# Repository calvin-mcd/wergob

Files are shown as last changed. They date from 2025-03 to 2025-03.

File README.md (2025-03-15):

# wergob

This is a pcb for the ergo board by _obabo called wergob!

## Layout

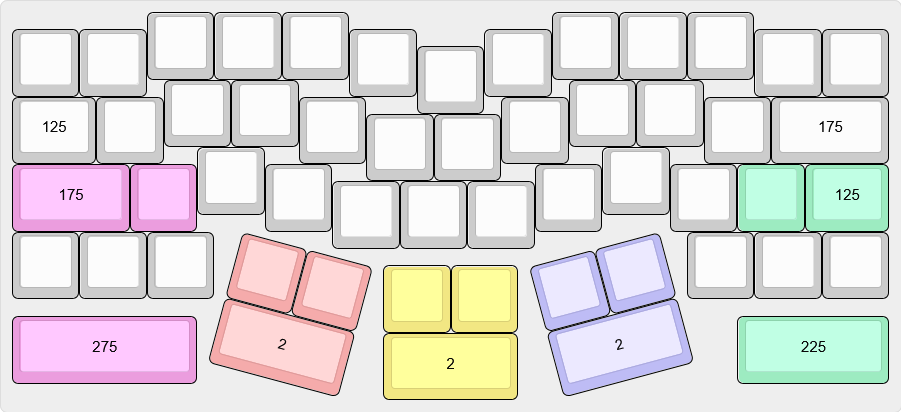
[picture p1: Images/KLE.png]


[Link](https://www.keyboard-layout-editor.com/#/gists/adf7cc06b15a428de764ebef3565cc50)

## Case

_obabo is designing a dedicated case for this unique layout!

## Todo

- [ ] order & test pcb
- [ ] design & test case
- [ ] create firmware

## Disclaimer

Please note that this project is a work in progress with no guarantees of a working outcome. No-one involved in this project is responsible for any usage issues that may arise. However, feel free to edit, modify and otherwise utilise these files.

## License

This project is released under the GPL v3 License. Please refer to the LICENCE file.

## Credits

big thanks to _obabo for the inspiring keyboard designs for our community! 

Any questions, contact Calvin\#0563 on Discord.

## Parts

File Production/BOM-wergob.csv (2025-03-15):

Comment | Designator | Footprint | LCSC | Quantity
10uF | C6 | C_0402_1005Metric | C15525 | 1
JST SH | J1 | JST_SH_SM04B-SRSS-TB_1x04-1MP_P1.00mm_Horizontal | C160404 | 1
10k | R1 | R_0402_1005Metric | C25744 | 1
100nF | C1,C2,C3,C4,C5,C7 | C_0402_1005Metric | C307331 | 6
1uF | C8,C9 | C_0402_1005Metric | C52923 | 2
XC6206PxxxMR-Regulator_Linear | U2 | SOT-23 | C5446 | 1
SKQGABE010 | SW1 | SW_Push_SPST_NO_Alps_SKRK | C561519 | 1
D_Small | D1,D10,D11,D12,D13,D14,D15,D16,D17,D18,D19,D2,D20,D21,D22,D23,D24,D25,D26,D27,D28,D29,D3,D30,D31,D32,D33,D34,D35,D36,D37,D38,D39,D4,D40,D41,D42,D43,D44,D45,D46,D47,D48,D49,D5,D6,D7,D8,D9 | D_SOD-123F | C64898 | 49
STM32F072CBT6 | U1 | LQFP-48_7x7mm_P0.5mm | C80488 | 1

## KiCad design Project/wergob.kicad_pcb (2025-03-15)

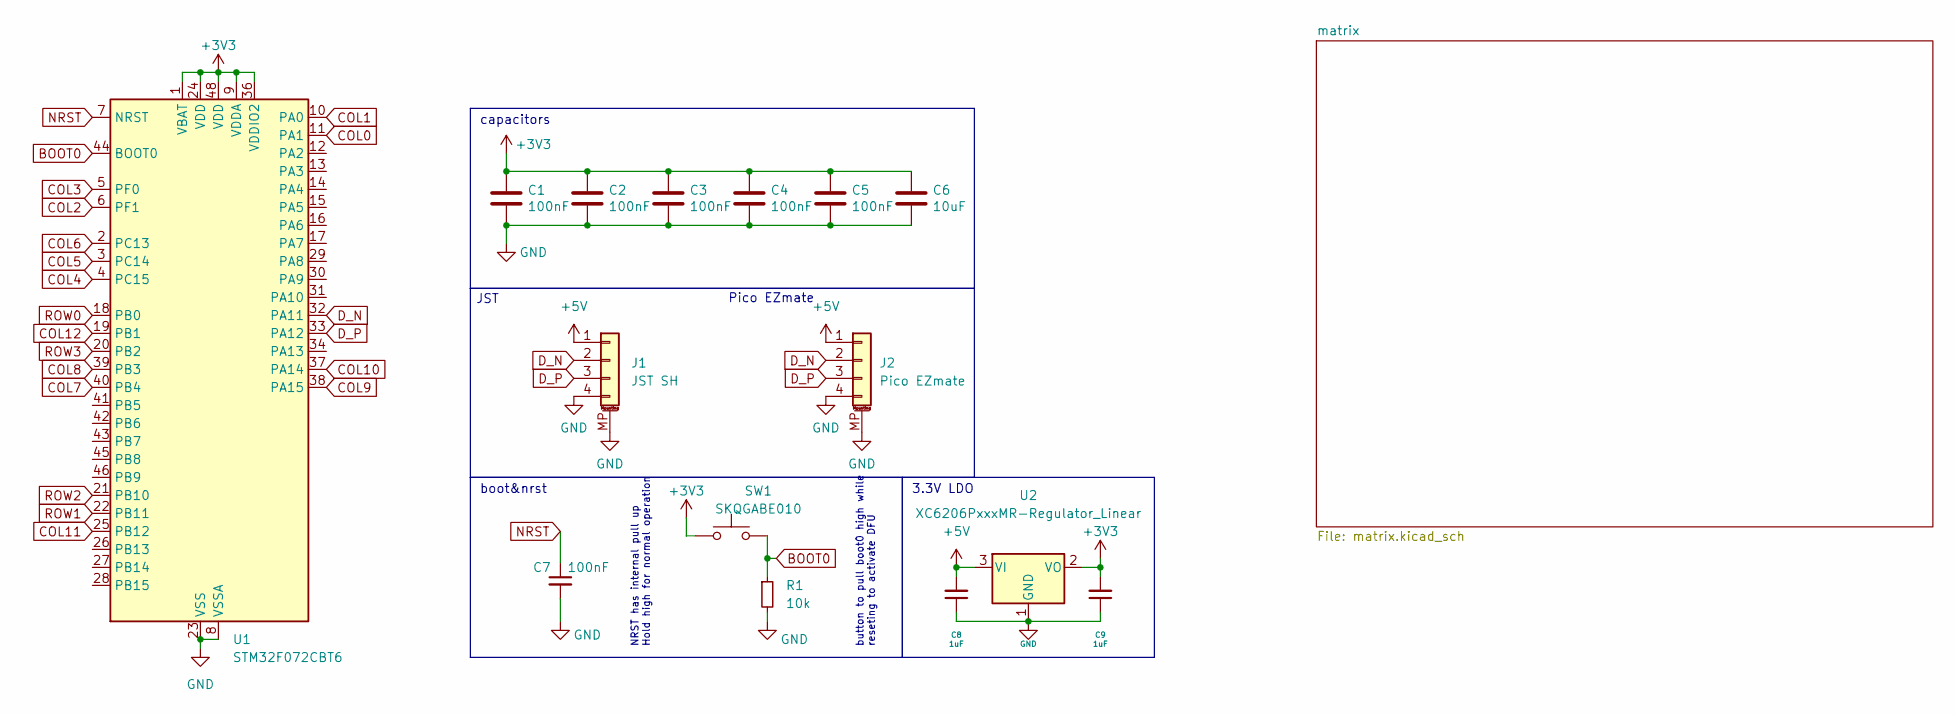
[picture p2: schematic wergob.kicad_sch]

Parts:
C1, C2, C3, C4, C5, C7: 100nF; C_0402_1005Metric; LCSC C307331
C6: 10uF; C_0402_1005Metric
C8, C9: 1uF; C_0402_1005Metric; LCSC C52923
J1: JST SH; JST_SH_SM04B-SRSS-TB_1x04-1MP_P1.00mm_Horizontal
J2: Pico EZmate; Molex_Pico-EZmate_78171-0004_1x04-1MP_P1.20mm_Vertical
R1: 10k; R_0402_1005Metric
SW1: SKQGABE010; SW_Push_SPST_NO_Alps_SKRK; LCSC C115351
U1: STM32F072CBT6; LQFP-48_7x7mm_P0.5mm; JlcRotOffset 90
U2: XC6206PxxxMR-Regulator_Linear; SOT-23; LCSC C5446

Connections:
+3V3: C1.1, C2.1, C3.1, C4.1, C5.1, C6.1, C9.2, SW1.1, U1.1 (VBAT), U1.9 (VDDA), U1.24 (VDD), U1.36 (VDDIO2), U1.48 (VDD), U2.2 (VO)
+5V: C8.2, J1.1, J2.1, U2.3 (VI)
BOOT0: R1.1, SW1.2, U1.44 (BOOT0)
COL0: U1.11 (PA1); also elsewhere on the board
COL1: U1.10 (PA0); also elsewhere on the board
COL2: U1.6 (PF1); also elsewhere on the board
COL3: U1.5 (PF0); also elsewhere on the board
COL4: U1.4 (PC15); also elsewhere on the board
COL5: U1.3 (PC14); also elsewhere on the board
COL6: U1.2 (PC13); also elsewhere on the board
COL7: U1.40 (PB4); also elsewhere on the board
COL8: U1.39 (PB3); also elsewhere on the board
COL9: U1.38 (PA15); also elsewhere on the board
COL10: U1.37 (PA14); also elsewhere on the board
COL11: U1.25 (PB12); also elsewhere on the board
COL12: U1.19 (PB1); also elsewhere on the board
D_N: J1.2, J2.2, U1.32 (PA11)
D_P: J1.3, J2.3, U1.33 (PA12)
GND: C1.2, C2.2, C3.2, C4.2, C5.2, C6.2, C7.2, C8.1, C9.1, J1.4, J1.MP (MountPin), J2.4, J2.MP (MountPin), R1.2, U1.8 (VSSA), U1.23 (VSS), U1.35 (VSS), U1.47 (VSS), U2.1 (GND)
NRST: C7.1, U1.7 (NRST)
ROW0: U1.18 (PB0); also elsewhere on the board
ROW1: U1.22 (PB11); also elsewhere on the board
ROW2: U1.21 (PB10); also elsewhere on the board
ROW3: U1.20 (PB2); also elsewhere on the board

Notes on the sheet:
JST
capacitors
NRST has internal pull up Hold high for normal operation
boot&nrst
button to pull boot0 high while reseting to activate DFU
Pico EZmate
3.3V LDO

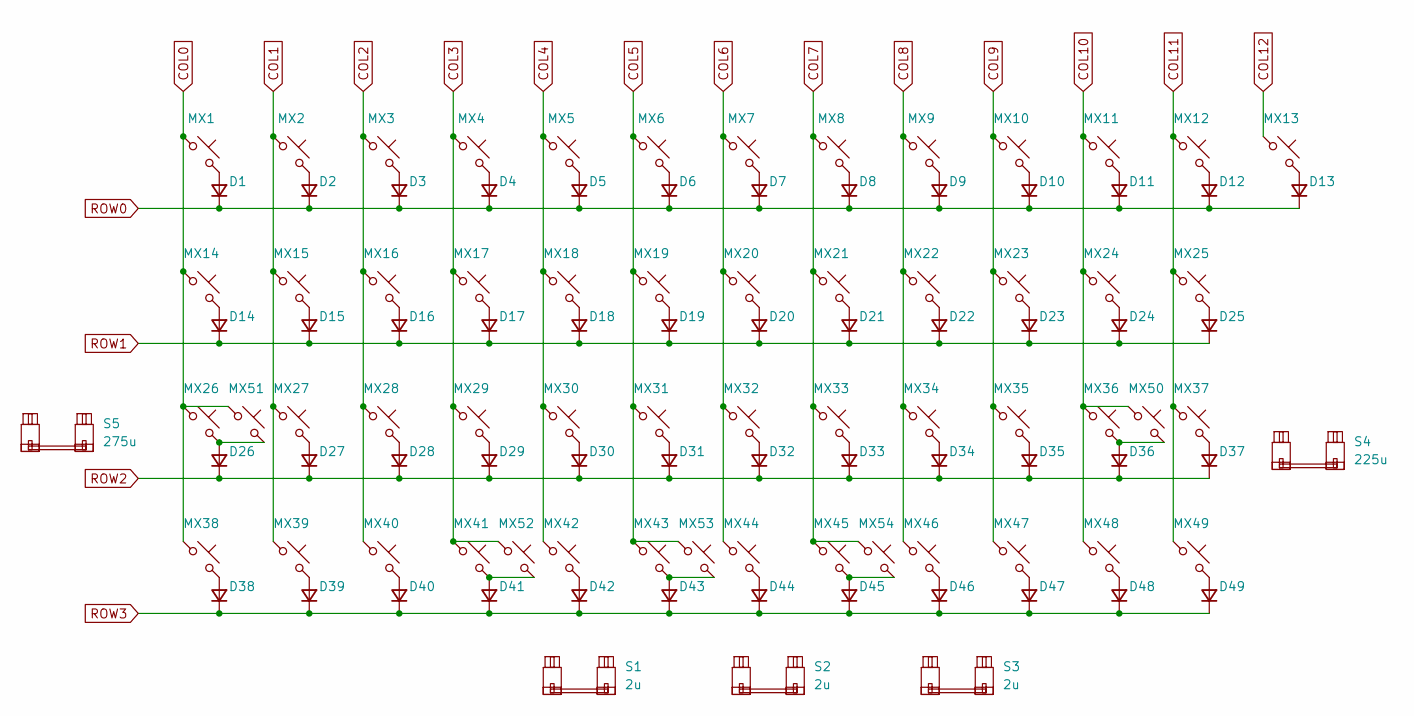
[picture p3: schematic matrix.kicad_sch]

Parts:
D1, D2, D3, D4, D5, D6, D7, D8, D9, D10, D11, D12, D13, D14, D15, D16, D17, D18, D19, D20, D21, D22, D23, D24, D25, D26, D27, D28, D29, D30, D31, D32, D33, D34, D35, D36, D37, D38, D39, D40, D41, D42, D43, D44, D45, D46, D47, D48, D49: D_Small; D_SOD-123F
MX1, MX2, MX3, MX4, MX5, MX6, MX7, MX8, MX9, MX10, MX11, MX12, MX13, MX15, MX16, MX17, MX18, MX19, MX20, MX21, MX22, MX23, MX24, MX27, MX28, MX29, MX30, MX31, MX32, MX33, MX34, MX35, MX36, MX38, MX39, MX40, MX41, MX42, MX43, MX44, MX45, MX46, MX47, MX48, MX49, MX50, MX51, MX52, MX53, MX54: MX_SW_solder; SW_MX_1u
MX14, MX37: MX_SW_solder; SW_MX_1.25u
MX25, MX26: MX_SW_solder; SW_MX_1.75u
S1, S2, S3: 2u; STAB_MX_P_2u
S4: 225u; STAB_MX_P_2.25u
S5: 275u; STAB_MX_P_2.75u

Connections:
COL0: MX1.1, MX14.1, MX26.1, MX38.1, MX51.1; also elsewhere on the board
COL1: MX2.1, MX15.1, MX27.1, MX39.1; also elsewhere on the board
COL2: MX3.1, MX16.1, MX28.1, MX40.1; also elsewhere on the board
COL3: MX4.1, MX17.1, MX29.1, MX41.1, MX52.1; also elsewhere on the board
COL4: MX5.1, MX18.1, MX30.1, MX42.1; also elsewhere on the board
COL5: MX6.1, MX19.1, MX31.1, MX43.1, MX53.1; also elsewhere on the board
COL6: MX7.1, MX20.1, MX32.1, MX44.1; also elsewhere on the board
COL7: MX8.1, MX21.1, MX33.1, MX45.1, MX54.1; also elsewhere on the board
COL8: MX9.1, MX22.1, MX34.1, MX46.1; also elsewhere on the board
COL9: MX10.1, MX23.1, MX35.1, MX47.1; also elsewhere on the board
COL10: MX11.1, MX24.1, MX36.1, MX48.1, MX50.1; also elsewhere on the board
COL11: MX12.1, MX25.1, MX37.1, MX49.1; also elsewhere on the board
COL12: MX13.1; also elsewhere on the board
unnamed: D1.2 (A), MX1.2
unnamed: D2.2 (A), MX2.2
unnamed: D3.2 (A), MX3.2
unnamed: D4.2 (A), MX4.2
unnamed: D5.2 (A), MX5.2
unnamed: D6.2 (A), MX6.2
unnamed: D7.2 (A), MX7.2
unnamed: D8.2 (A), MX8.2
unnamed: D9.2 (A), MX9.2
unnamed: D10.2 (A), MX10.2
unnamed: D11.2 (A), MX11.2
unnamed: D12.2 (A), MX12.2
unnamed: D13.2 (A), MX13.2
unnamed: D14.2 (A), MX14.2
unnamed: D15.2 (A), MX15.2
unnamed: D16.2 (A), MX16.2
unnamed: D17.2 (A), MX17.2
unnamed: D18.2 (A), MX18.2
unnamed: D19.2 (A), MX19.2
unnamed: D20.2 (A), MX20.2
unnamed: D21.2 (A), MX21.2
unnamed: D22.2 (A), MX22.2
unnamed: D23.2 (A), MX23.2
unnamed: D24.2 (A), MX24.2
unnamed: D25.2 (A), MX25.2
unnamed: D26.2 (A), MX26.2, MX51.2
unnamed: D27.2 (A), MX27.2
unnamed: D28.2 (A), MX28.2
unnamed: D29.2 (A), MX29.2
unnamed: D30.2 (A), MX30.2
unnamed: D31.2 (A), MX31.2
unnamed: D32.2 (A), MX32.2
unnamed: D33.2 (A), MX33.2
unnamed: D34.2 (A), MX34.2
unnamed: D35.2 (A), MX35.2
unnamed: D36.2 (A), MX36.2, MX50.2
unnamed: D37.2 (A), MX37.2
unnamed: D38.2 (A), MX38.2
unnamed: D39.2 (A), MX39.2
unnamed: D40.2 (A), MX40.2
unnamed: D41.2 (A), MX41.2, MX52.2
unnamed: D42.2 (A), MX42.2
unnamed: D43.2 (A), MX43.2, MX53.2
unnamed: D44.2 (A), MX44.2
unnamed: D45.2 (A), MX45.2, MX54.2
unnamed: D46.2 (A), MX46.2
unnamed: D47.2 (A), MX47.2
unnamed: D48.2 (A), MX48.2
unnamed: D49.2 (A), MX49.2
ROW0: D1.1 (K), D2.1 (K), D3.1 (K), D4.1 (K), D5.1 (K), D6.1 (K), D7.1 (K), D8.1 (K), D9.1 (K), D10.1 (K), D11.1 (K), D12.1 (K), D13.1 (K); also elsewhere on the board
ROW1: D14.1 (K), D15.1 (K), D16.1 (K), D17.1 (K), D18.1 (K), D19.1 (K), D20.1 (K), D21.1 (K), D22.1 (K), D23.1 (K), D24.1 (K), D25.1 (K); also elsewhere on the board
ROW2: D26.1 (K), D27.1 (K), D28.1 (K), D29.1 (K), D30.1 (K), D31.1 (K), D32.1 (K), D33.1 (K), D34.1 (K), D35.1 (K), D36.1 (K), D37.1 (K); also elsewhere on the board
ROW3: D38.1 (K), D39.1 (K), D40.1 (K), D41.1 (K), D42.1 (K), D43.1 (K), D44.1 (K), D45.1 (K), D46.1 (K), D47.1 (K), D48.1 (K), D49.1 (K); also elsewhere on the board

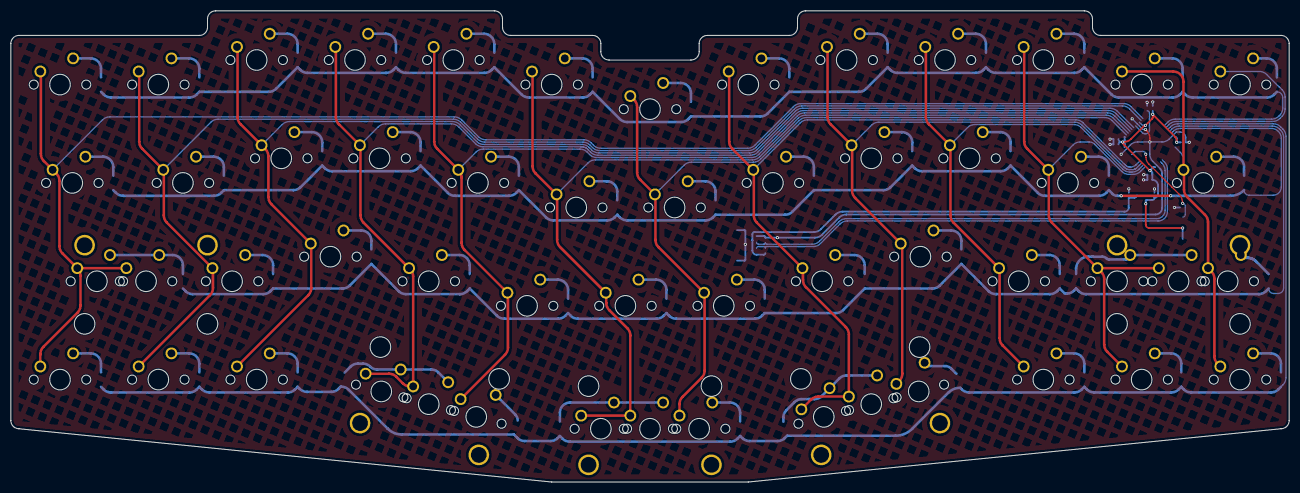
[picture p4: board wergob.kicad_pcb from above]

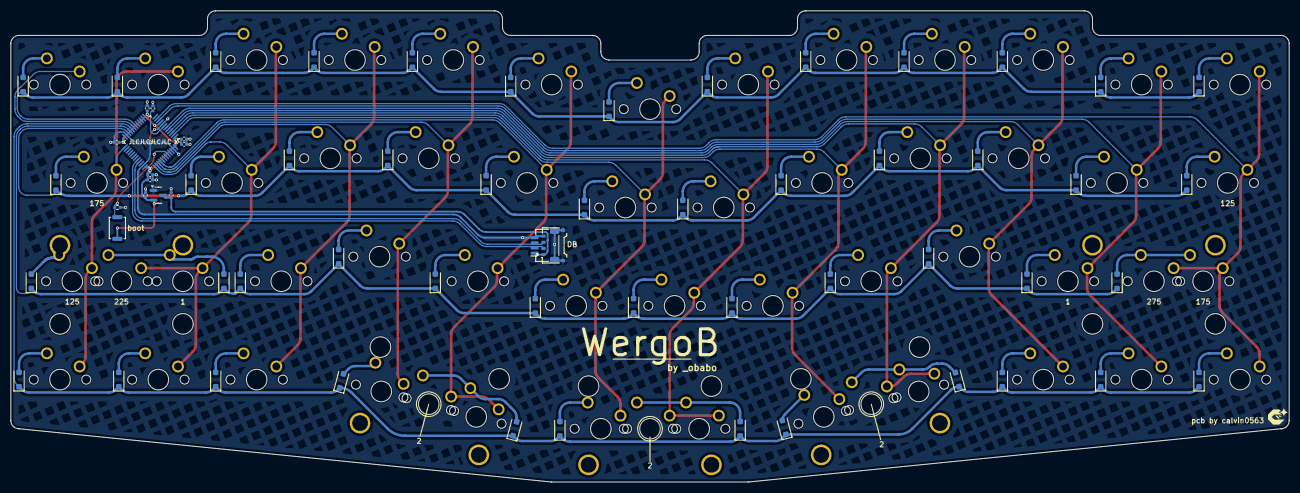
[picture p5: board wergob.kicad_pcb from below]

Board: 2 copper layers, 247.6 x 91.3 mm, 123 parts (64 on the bottom side), 73 nets.
